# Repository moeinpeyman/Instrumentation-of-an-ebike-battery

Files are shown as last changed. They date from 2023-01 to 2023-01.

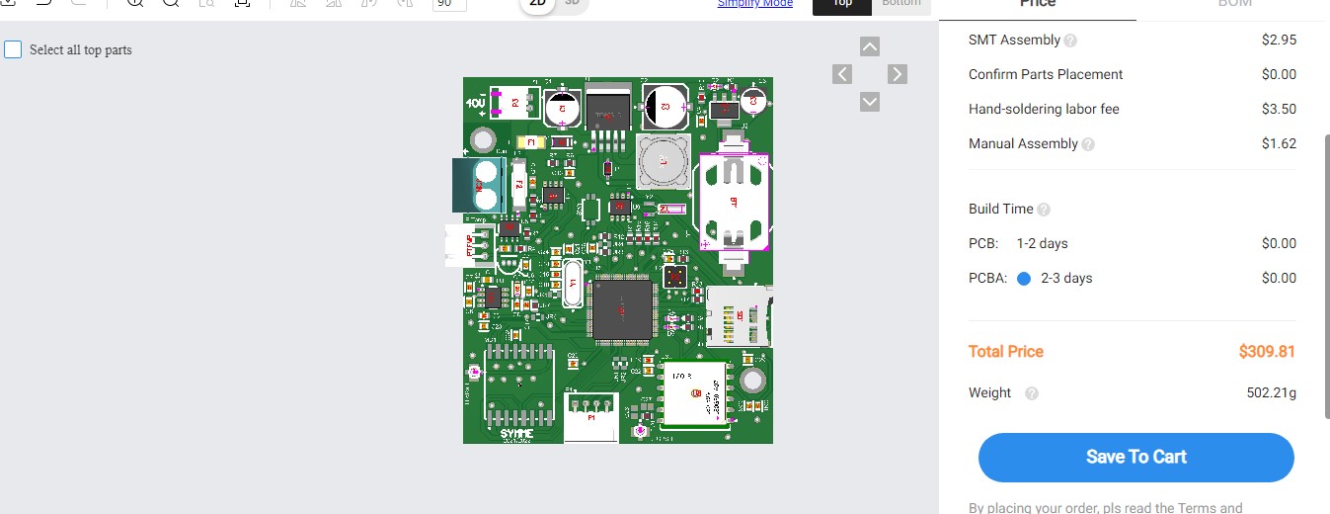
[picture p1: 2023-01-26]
PCB/JLPCB/Screenshot 2022-09-02 162259.jpg

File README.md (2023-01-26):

## PCB is designed in Altium designer and ordered from JLCPCB.



## ST-LINK/V2 for upload the code:



## The installed PCB in the e-bike battery:



## ADC configuration in STM32CubeIDE:



## SPI configuration for SD card in STM32CubeIDE:
ref:https://01001000.xyz/2020-08-09-Tutorial-STM32CubeIDE-SD-card/



## The Main.c code is available here:

https://github.com/moeinpeyman/Instrumentation-of-an-ebike-battery/blob/main/Ebike_battery_data_logging/Core/Src/main.c

## Testing roath:



## Result:


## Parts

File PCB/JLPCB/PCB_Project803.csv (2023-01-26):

Comment | Description | Designator | Footprint | LibRef | Quantity | LCSC part#
796136-1 |  | BT1 | TECO-796136-1_V | CMP-1684-00006-2 | 1 | C70377
100uF |  | C1 | FP-UWT1H101MNL1GS-MFG | CMP-2000-07373-2 | 1 | C445063
1000uF |  | C2 | FP-SVPF-F12-MFG | CMP-05427-000075-1 | 1 | C236289
100uf |  | C3 | FP-SC-MFG | CMP-05427-000027-1 | 1 | C128464
10uF |  | C4, C6, C30, C32 | FP-GRM21B-0_1-IPC_C | CMP-2007-03453-2 | 4 | C77075
1uF |  | C5 | FP-T491A105K016AT-MFG | CMP-2000-07186-2 | 1 | C116269
0.1uF |  | C7, C8, C9, C13, C19, C20, C21, C22, C23, C29, C31 | FP-C0805C-DN-MFG | CMP-2100-03606-3, CMP-2007-00279-2 | 11 | C49678
1nf |  | C10, C11, C12 | CAPC2013X70X45NL10T25 | CMP-2100-03606-3 | 3 | C303890
15pF |  | C14, C15 | FP-C0805C-DN-MFG | CMP-2007-00279-2 | 2 | C396747
10nF |  | C16, C25 | FP-C0805C-DN-MFG | CMP-2007-00279-2 | 2 | C188188
1uF |  | C17, C26 | FP-C0805C-DN-MFG | CMP-2007-00279-2 | 2 | C89190
100nF |  | C18 | FP-C0805C-DN-MFG | CMP-2007-00279-2 | 1 | C49678
4.7uF |  | C24 | FP-C0805C-DN-MFG | CMP-2007-00279-2 | 1 | C215908
0.1uF |  | C33 | FP-CC0805-0_85-MFG | CMP-2100-03606-3 | 1 | C49678
1N4007 SMD |  | D1 | FP-1N4007_SMD-IPC_C | CMP-12389-000001-1 | 1 | C727081
APT2012MGC |  | D2, D4, D5 | FP-APT2012MGC-MFG | CMP-1426-00010-2 | 3 | C138557
1N5822US |  | D3 | MCSM-D-5B-2_L | CMP-0303-00003-3 | 1 | C402219
1.5A |  | F1 | FP-0679H-MFG | CMP-2000-05188-2 | 1 | C178994
20A |  | F2 | FP-0456-MFG | CMP-08605-000068-1 | 1 | C99552
73412-0110 |  | JGPS1, JLoRa1 | MOLX-73412-0110_V | CMP-1676-00003-1 | 2 | C411563
PC Terminal Block |  | JCin | PHOE-1714955_V | CMP-2000-05797-1 | 1 | C480584
0R |  | JR3, JR7 | FP-RMCF0805-MFG | CMP-26527-000017-1 | 6 | C25275
150 µH |  | L1 | WE-PD-XL | CMP-0227-00206-1 | 1 | C169397
RFM95W-868S2 |  | MD1 | FP-RFM95W-868S2-MFG | CMP-204316-000001-1 | 1 | C2844472
USART Interface Port |  | P1 | JST-S4B-XH-A(LF)(SN)_V | CMP-1755-00007-1 | 1 | C163037
HTSW-102-07-G-D |  | P2 | FP-HTSW-102-07-G-D-MFG | CMP-02766-000010-1 | 1 | C66690
S2B-XH-A(LF)(SN) |  | P3 | JST-S2B-XH-A(LF)(SN)_V | CMP-1755-00005-1 | 1 | C157931
S3B-XH-A(LF)(SN) |  | PTemp | JST-S3B-XH-A(LF)(SN)_V | CMP-1755-00006-1 | 1 | C157928
330R |  | R1, R8, R9 | FP-CRCW0805-e3-MFG | CMP-02407-004193-1 | 3 | C17630
5.6K |  | R2, R3, R4, R5 | FP-CRCW0805-e3-MFG | CMP-02407-004193-1 | 4 | C4382
510K |  | R6 | FP-CRCW0805-e3-MFG | CMP-02407-004193-1 | 1 | C17724
30K |  | R7 | FP-CRCW0805-e3-MFG | CMP-02407-004193-1 | 1 | C422839
0R |  | R10, R19 | FP-CRCW0805-e3-MFG | CMP-02407-004193-1 | 2 | C25275
10K |  | R11, R12, R13, R14, R15, R16, R17, R18 | FP-CRCW0805-e3-MFG | CMP-02407-004193-1 | 8 | C478887
473521001 |  | SD1 | MOLX-473521001_V | CMP-2000-05848-1 | 1 | C381079
LM2576-5.0WU |  | U1 | FP-TO263-5LD-PL-1-MFG | CMP-0069-00269-3 | 1 | C77782
LM1117IMP-3.3/NOPB |  | U2 | DCY0004A_N | CMP-0062-01631-4 | 1 | C126027
REF192GSZ |  | U3 | ADI-R-8_M | CMP-0784-00133-1 | 1 | C27314
LM358MX/NOPB |  | U4 | D0008A_L | CMP-2000-07568-1 | 1 | C16416
ACS712ELCTR-20A-T |  | U5 | FP-LC-8-IPC_C | CMP-0826-00001-2 | 1 | C10681
STM32F103VET6TR |  | U7 | STM-LQFP100_L | CMP-0237-00166-3 | 1 | C8314
L80-M39 |  | U8 | QUEC-L80-M39-12_V | CMP-2000-05325-1 | 1 | C133488
DS1307Z+T&R |  | U9 | S8+2_L | CMP-0254-00305-1 | 1 | C9868
8Mhz |  | Y1 | FOX-FOXSLF080-20 | CMP-1749-00002-1 | 1 | C295071
AB26TRB-32.768KHZ-T |  | Y2 | FP-AB26TRB-MFG | CMP-27762-006068-1 | 1 | C179645

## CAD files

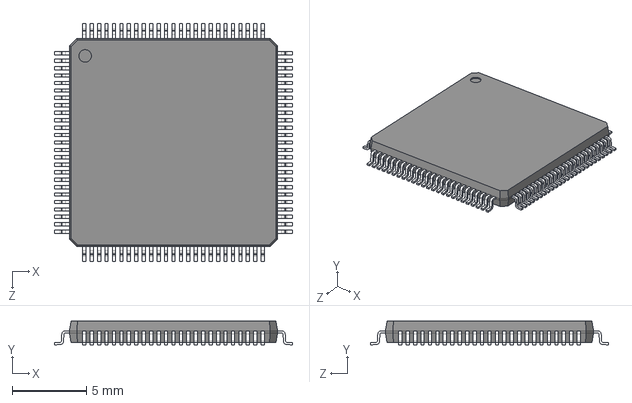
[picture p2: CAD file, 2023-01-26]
PCB/STM32F103VDT7.STEP
16.0 x 1.60 x 16.0 mm

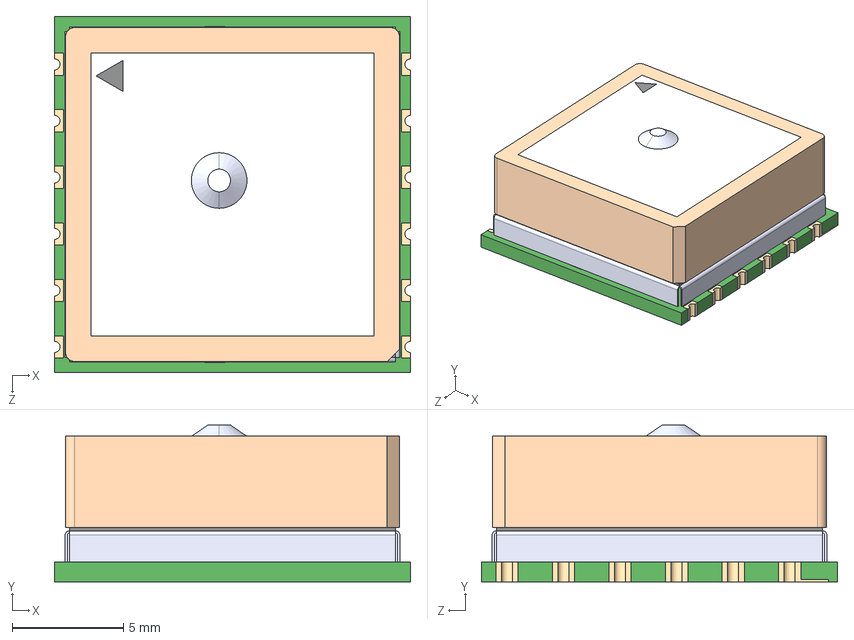
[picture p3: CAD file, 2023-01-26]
PCB/L80-M39--3DModel-STEP-56544.STEP
16.0 x 7.05 x 16.0 mm

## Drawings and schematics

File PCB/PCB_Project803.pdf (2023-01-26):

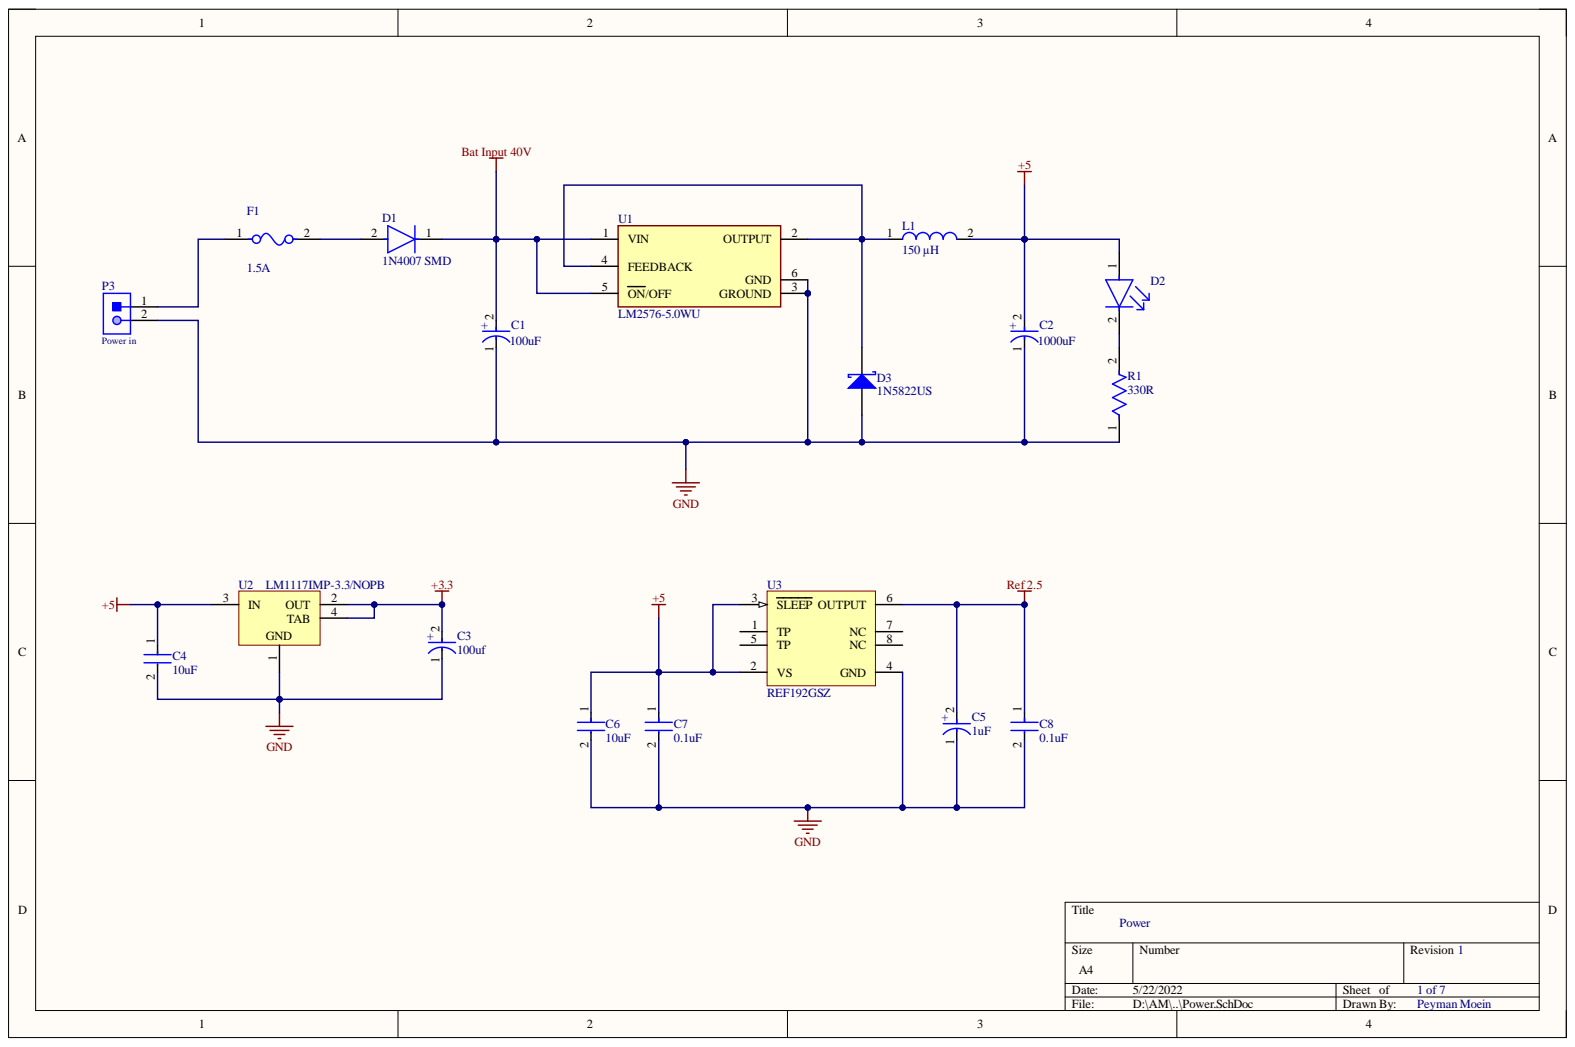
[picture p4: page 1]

FEEDBACK 4
GND ON/OFF 5 | 6

Size A4 | Number | Revision 1

Date: 5/22/2022 | Sheet of 1 of 7
File: D:\AM\..\Power.SchDoc | Drawn By: Peyman Moein

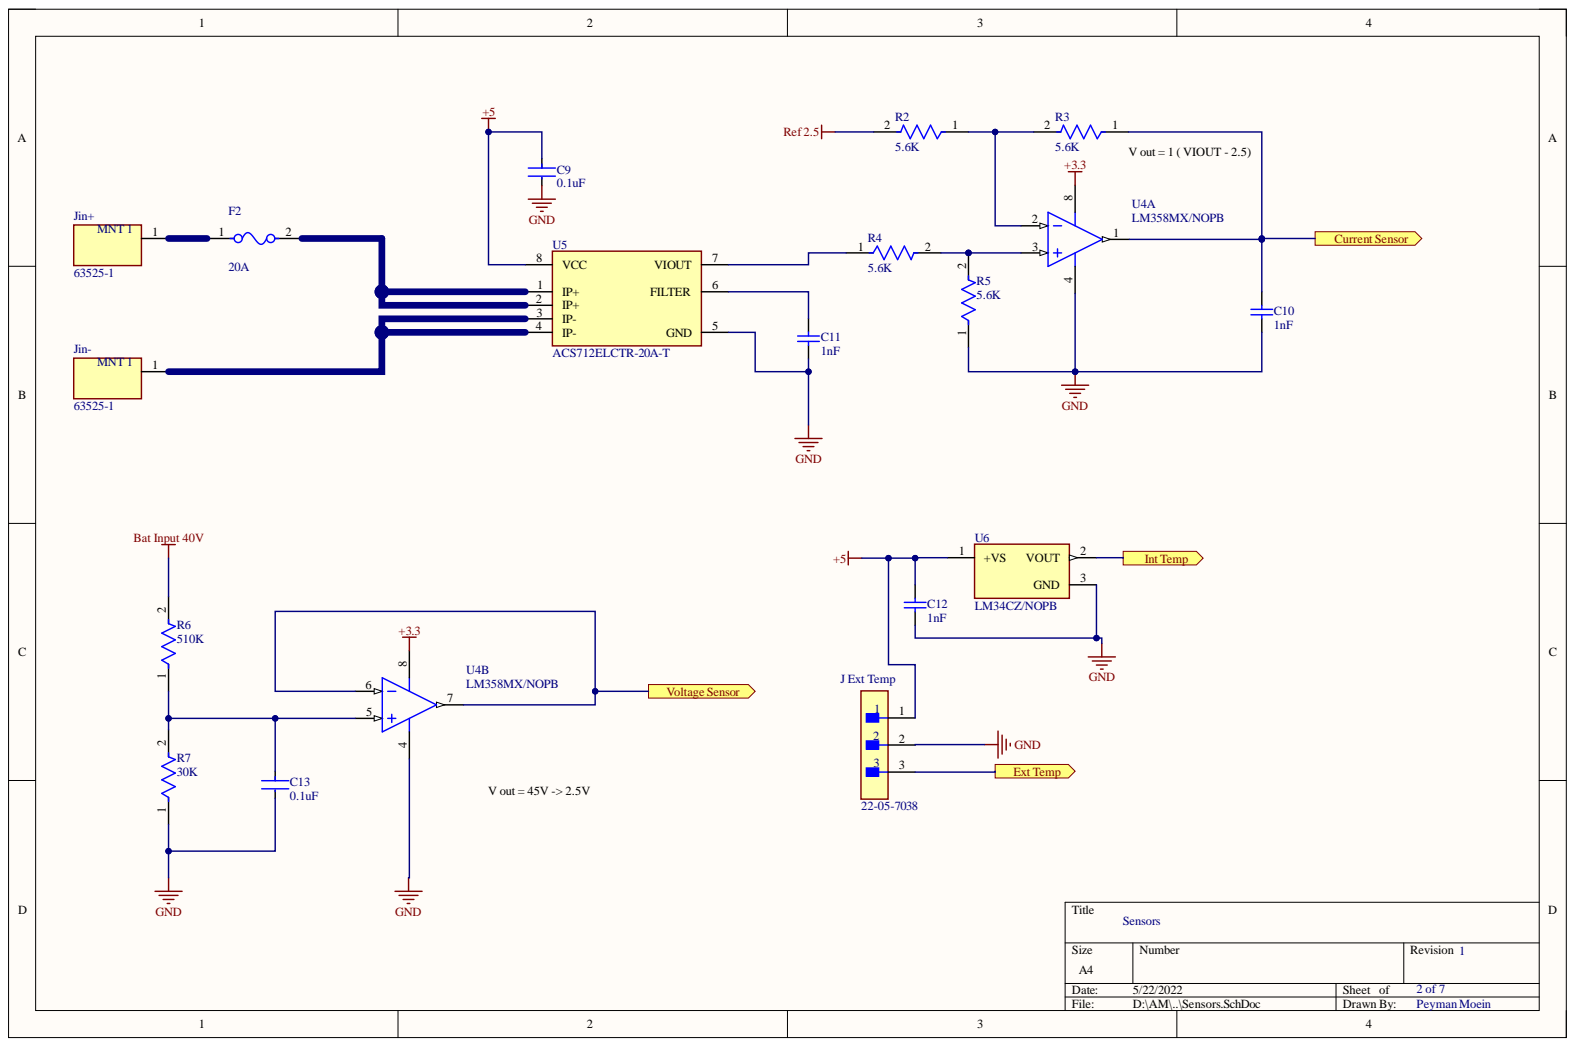
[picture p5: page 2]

Size A4 | Number | Revision 1

Date: 5/22/2022 | 2 of 7 Sheet of
File: D:\AM\..\Sensors.SchDoc | Drawn By: Peyman Moein

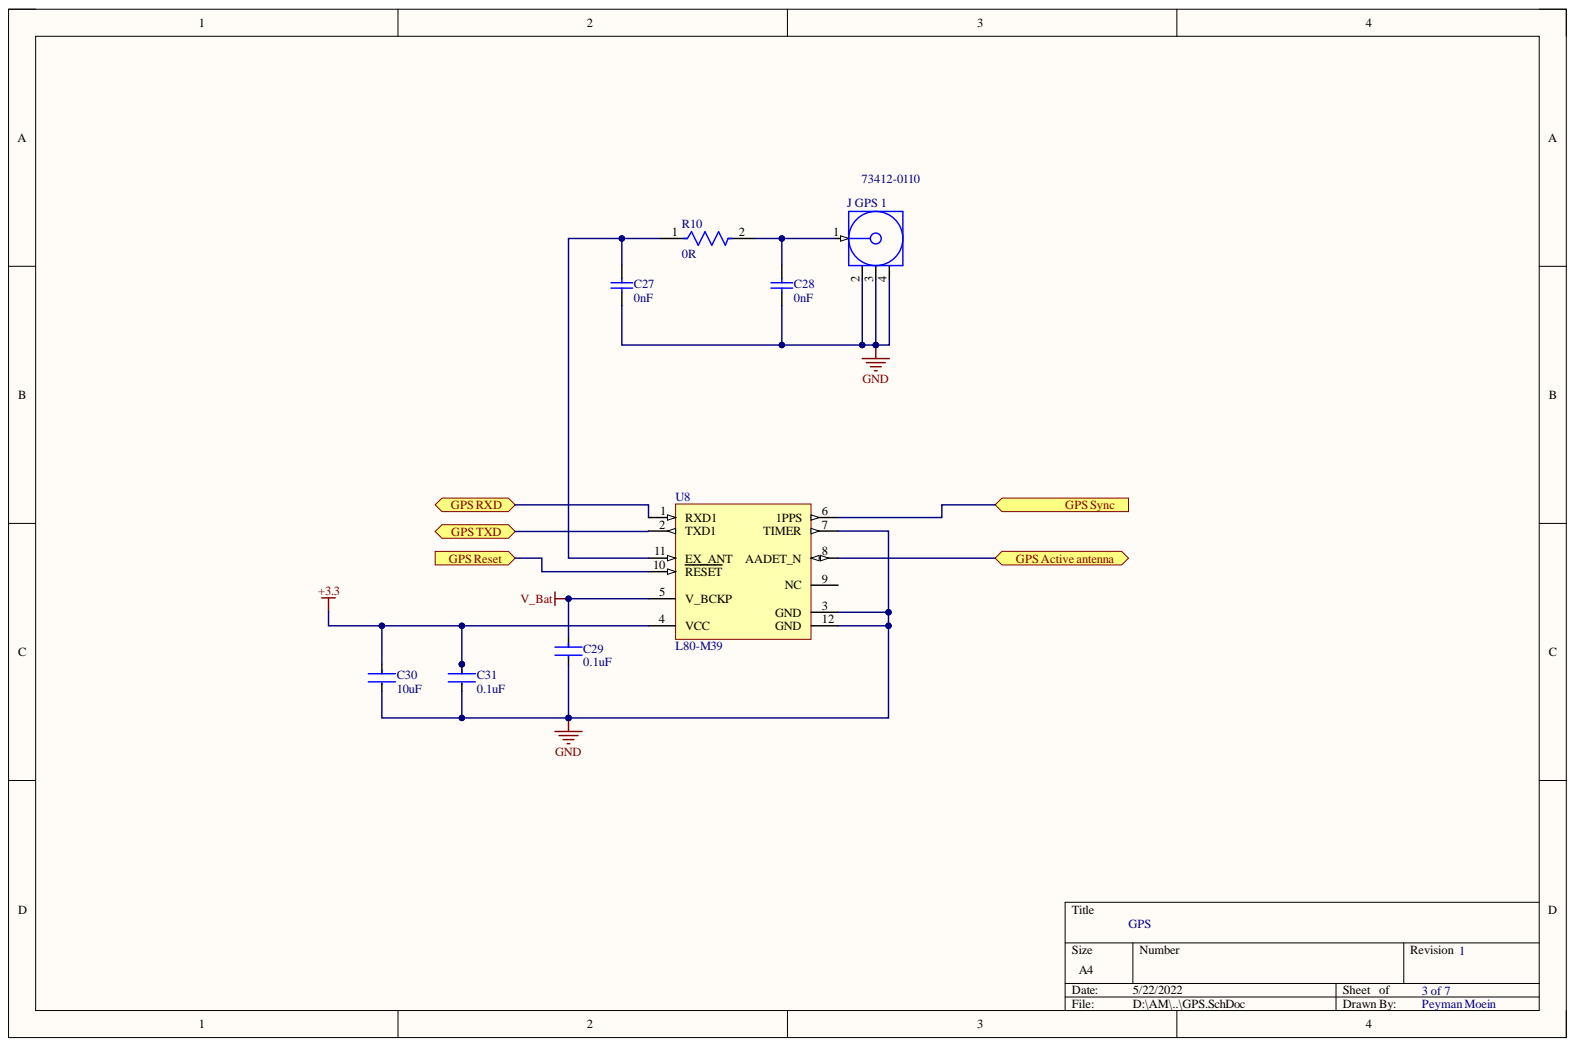
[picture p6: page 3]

Size A4 | Number | Revision 1

Date: 5/22/2022 | Sheet of 3 of 7
File: D:\AM\..\GPS.SchDoc | Drawn By: Peyman Moein

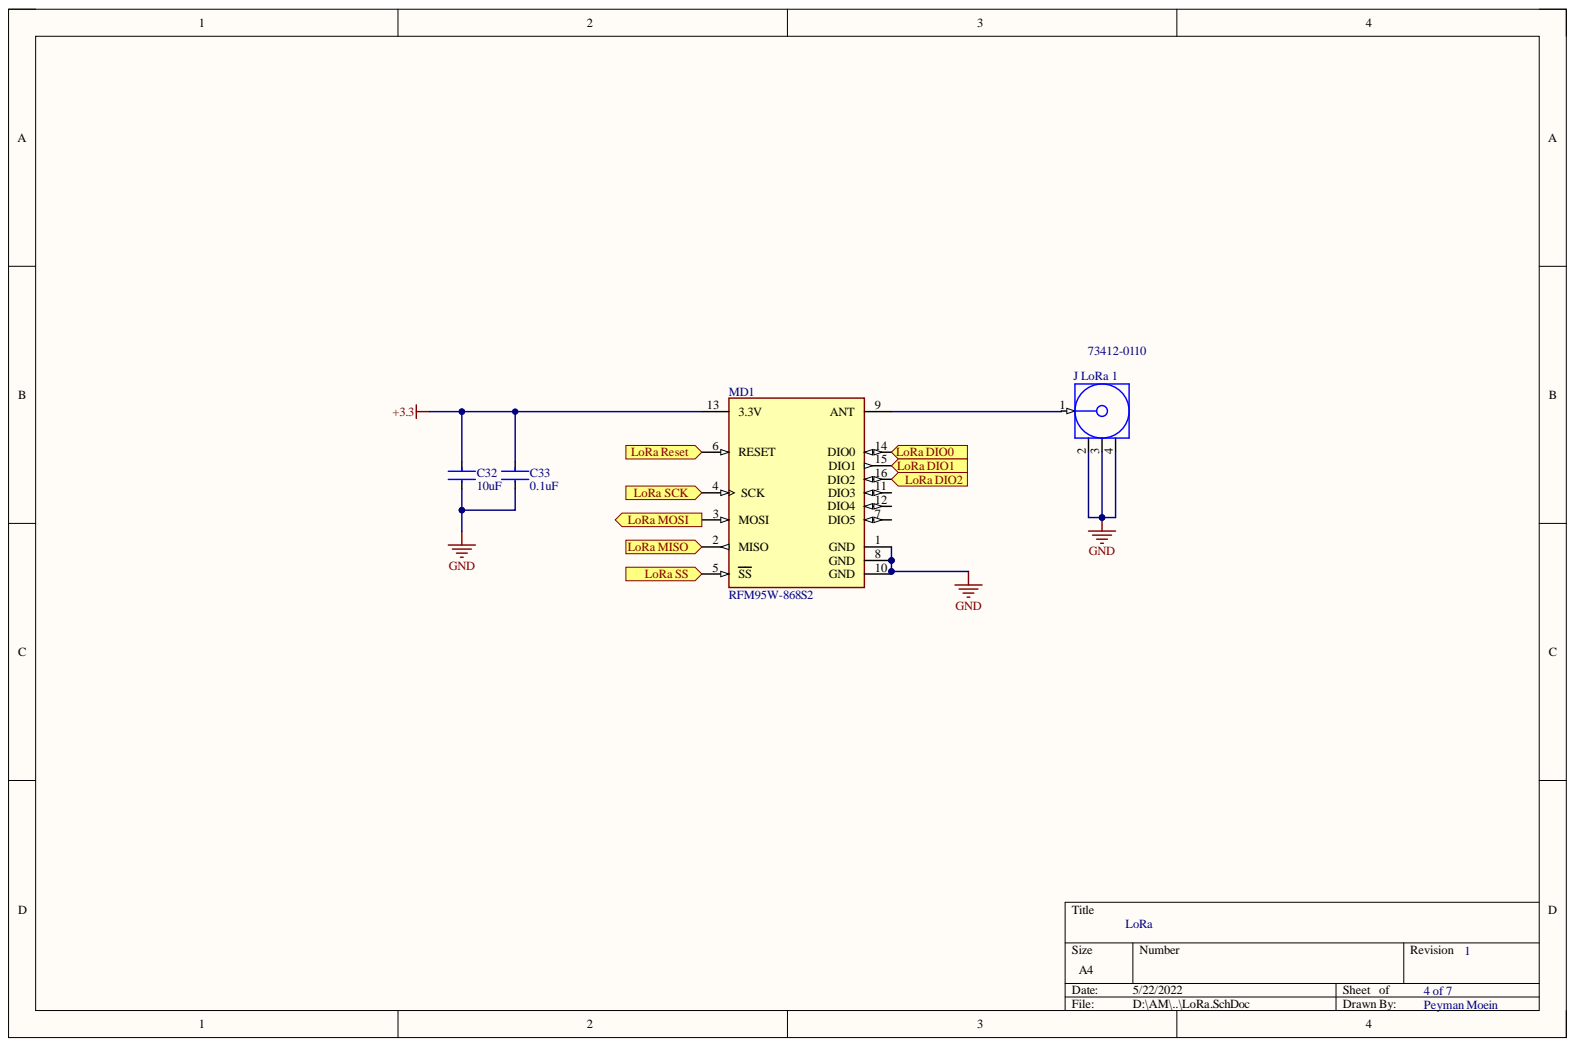
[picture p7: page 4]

Size A4 | Number | Revision 1

Date: 5/22/2022 | Sheet of 4 of 7
File: D:\AM\..\LoRa.SchDoc | Drawn By: Peyman Moein

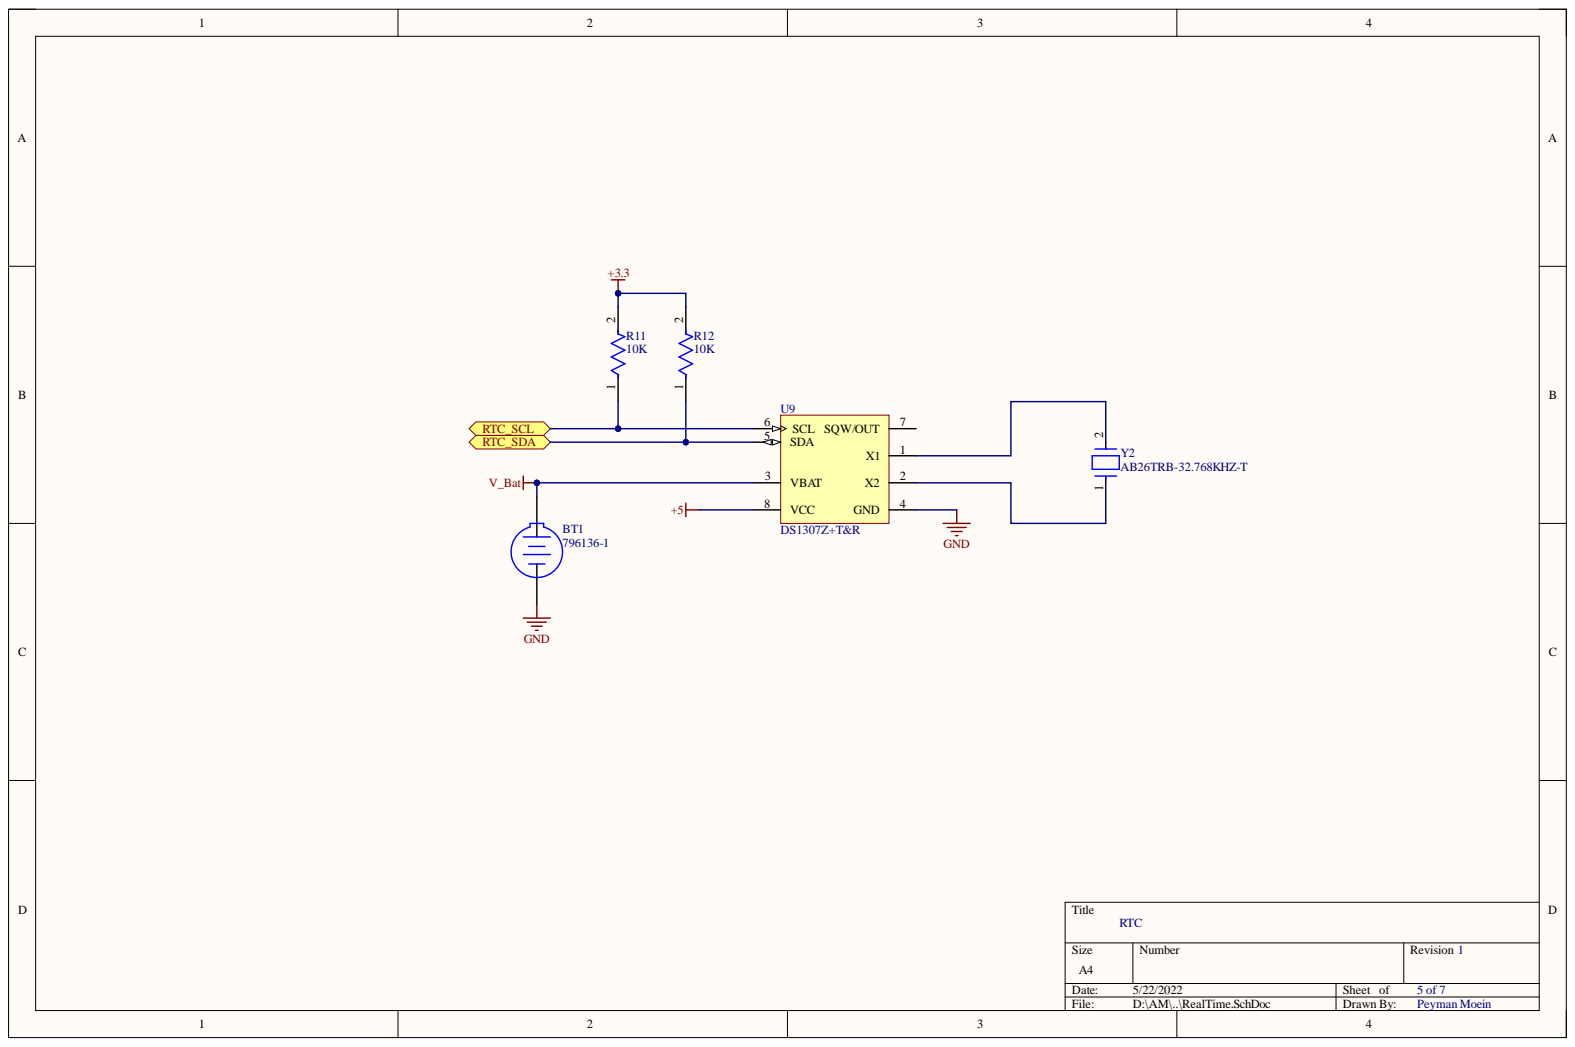
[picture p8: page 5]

Siz e A4 | Numb e r | R evisio n 1

Da te : 5/22/202 2 | She et of 5 of 7
File : D:\AM\. .\R e alTime . S c hD o c | Dr awn B y : P eyman Moe in

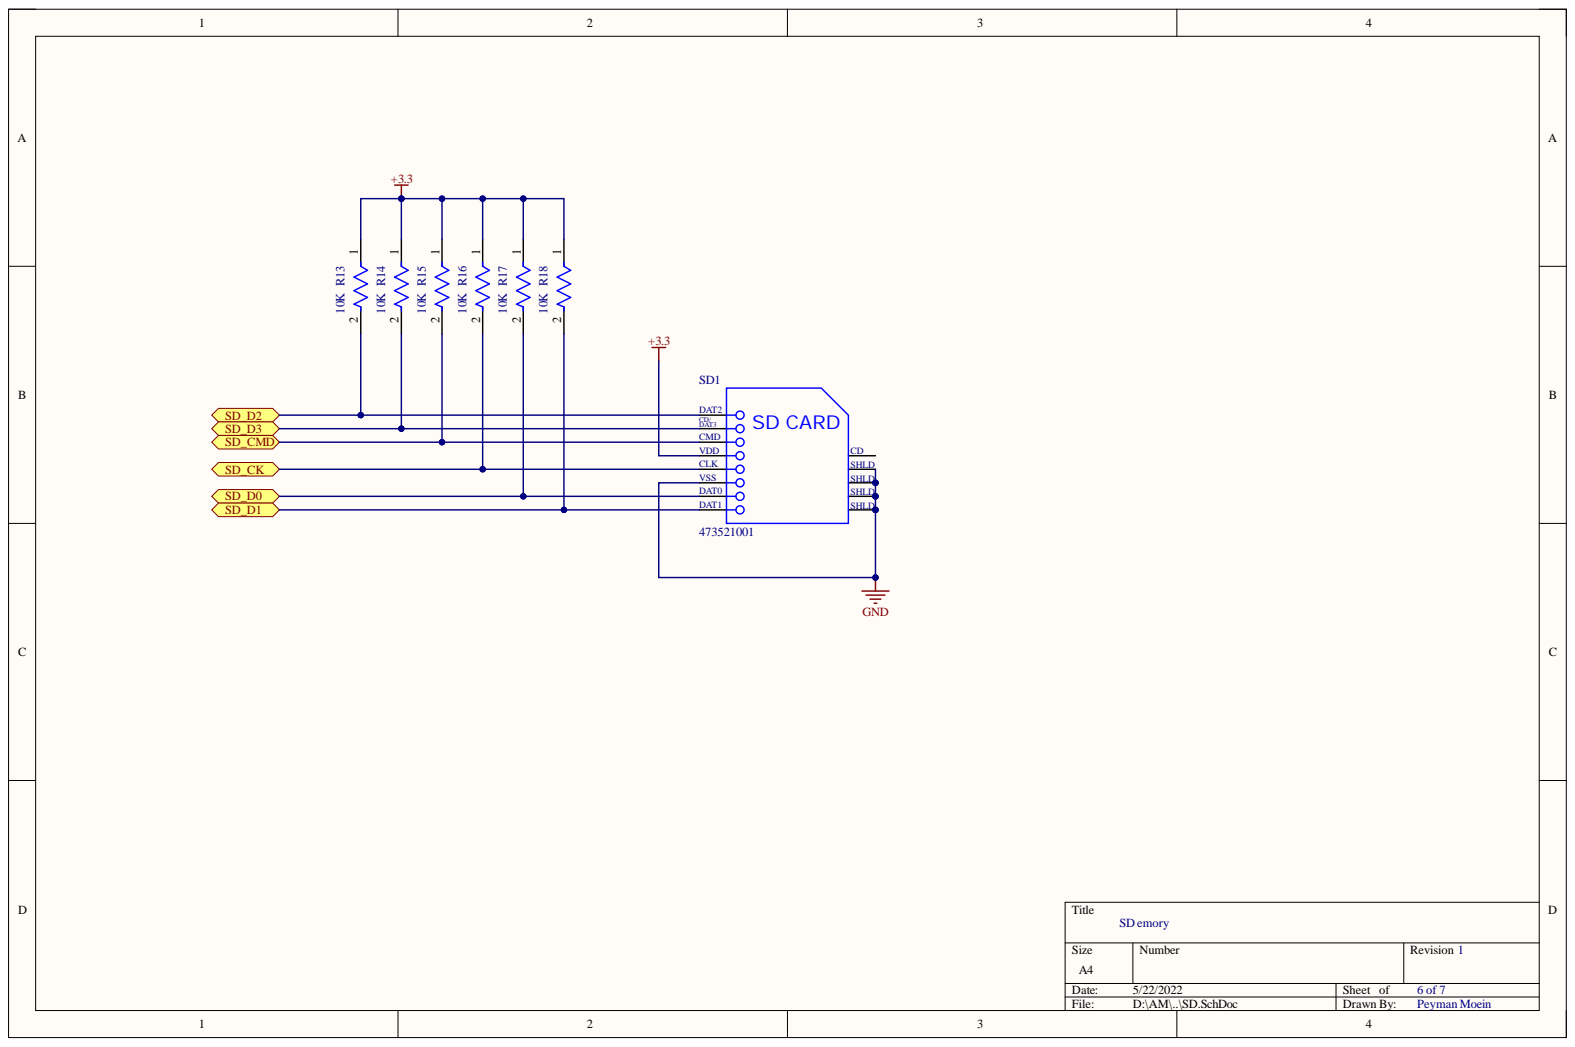
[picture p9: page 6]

Siz e A4 | Numb e r | R evisio n 1

Da te : 5/22/202 2 | She et of 6 of 7
File : D:\AM\. .\SD. S c hD o c | Dr awn B y : P eyman Moe in

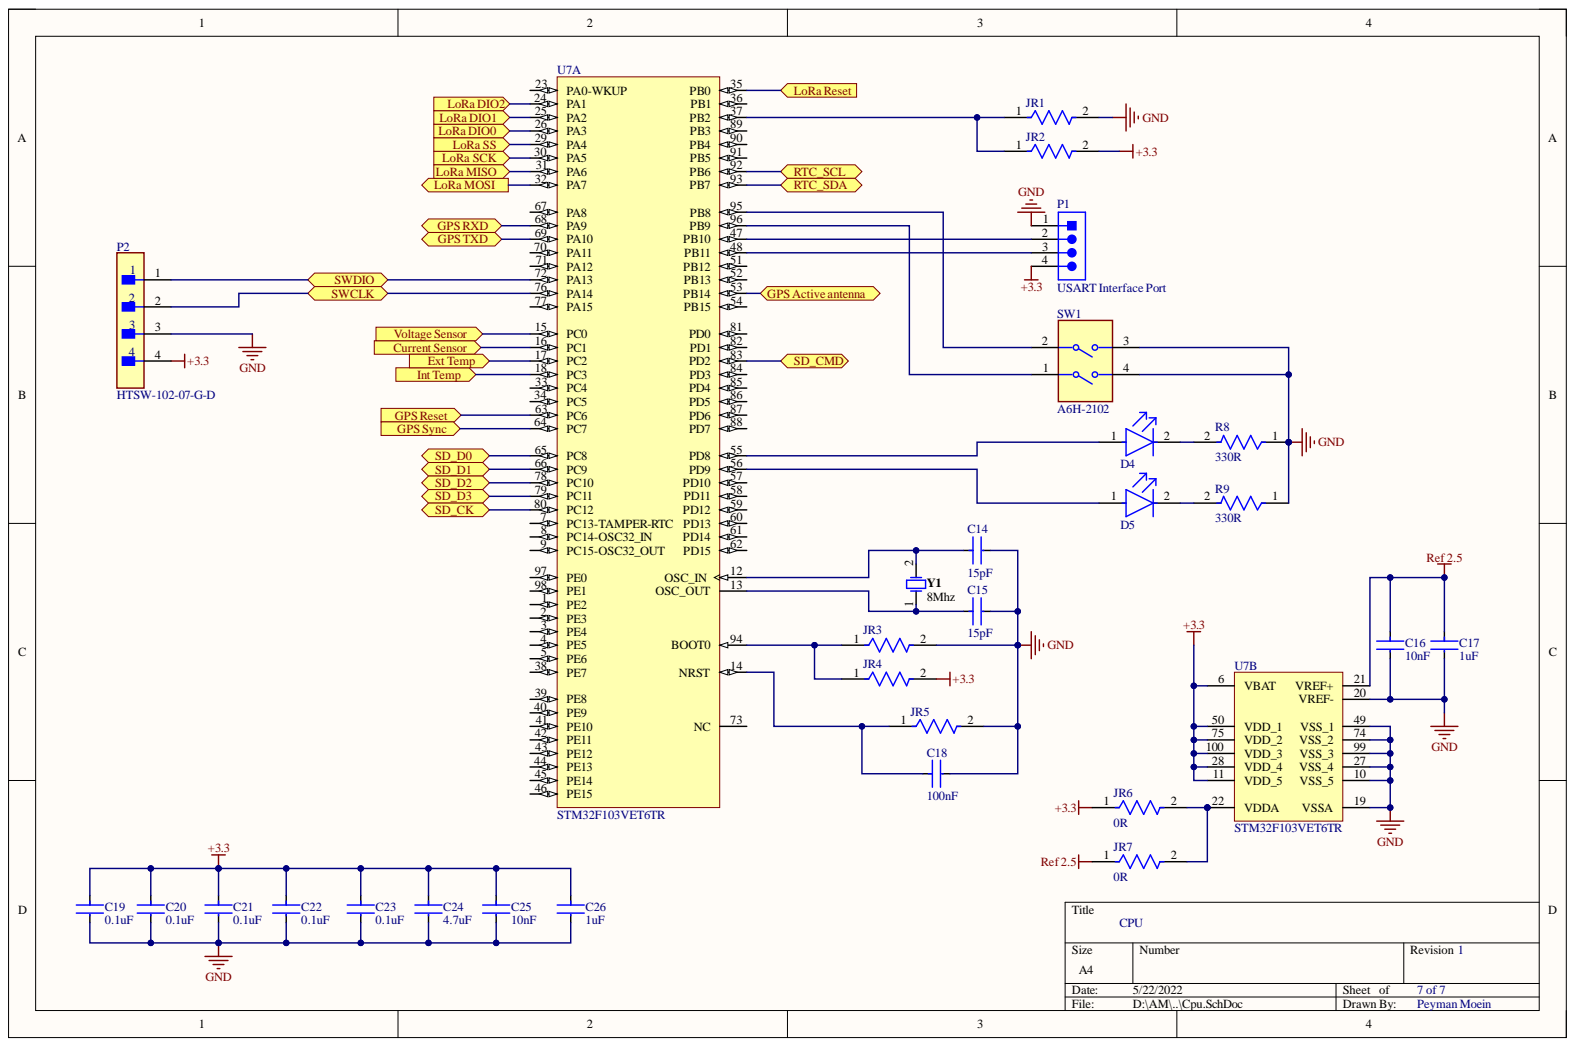
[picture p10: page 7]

SD_CMD | 1 | 4

Size A4 | Number | Revision 1

Date: 5/22/2022 | Sheet of 7 of 7
File: D:\AM\..\Cpu.SchDoc | Drawn By: Peyman Moein

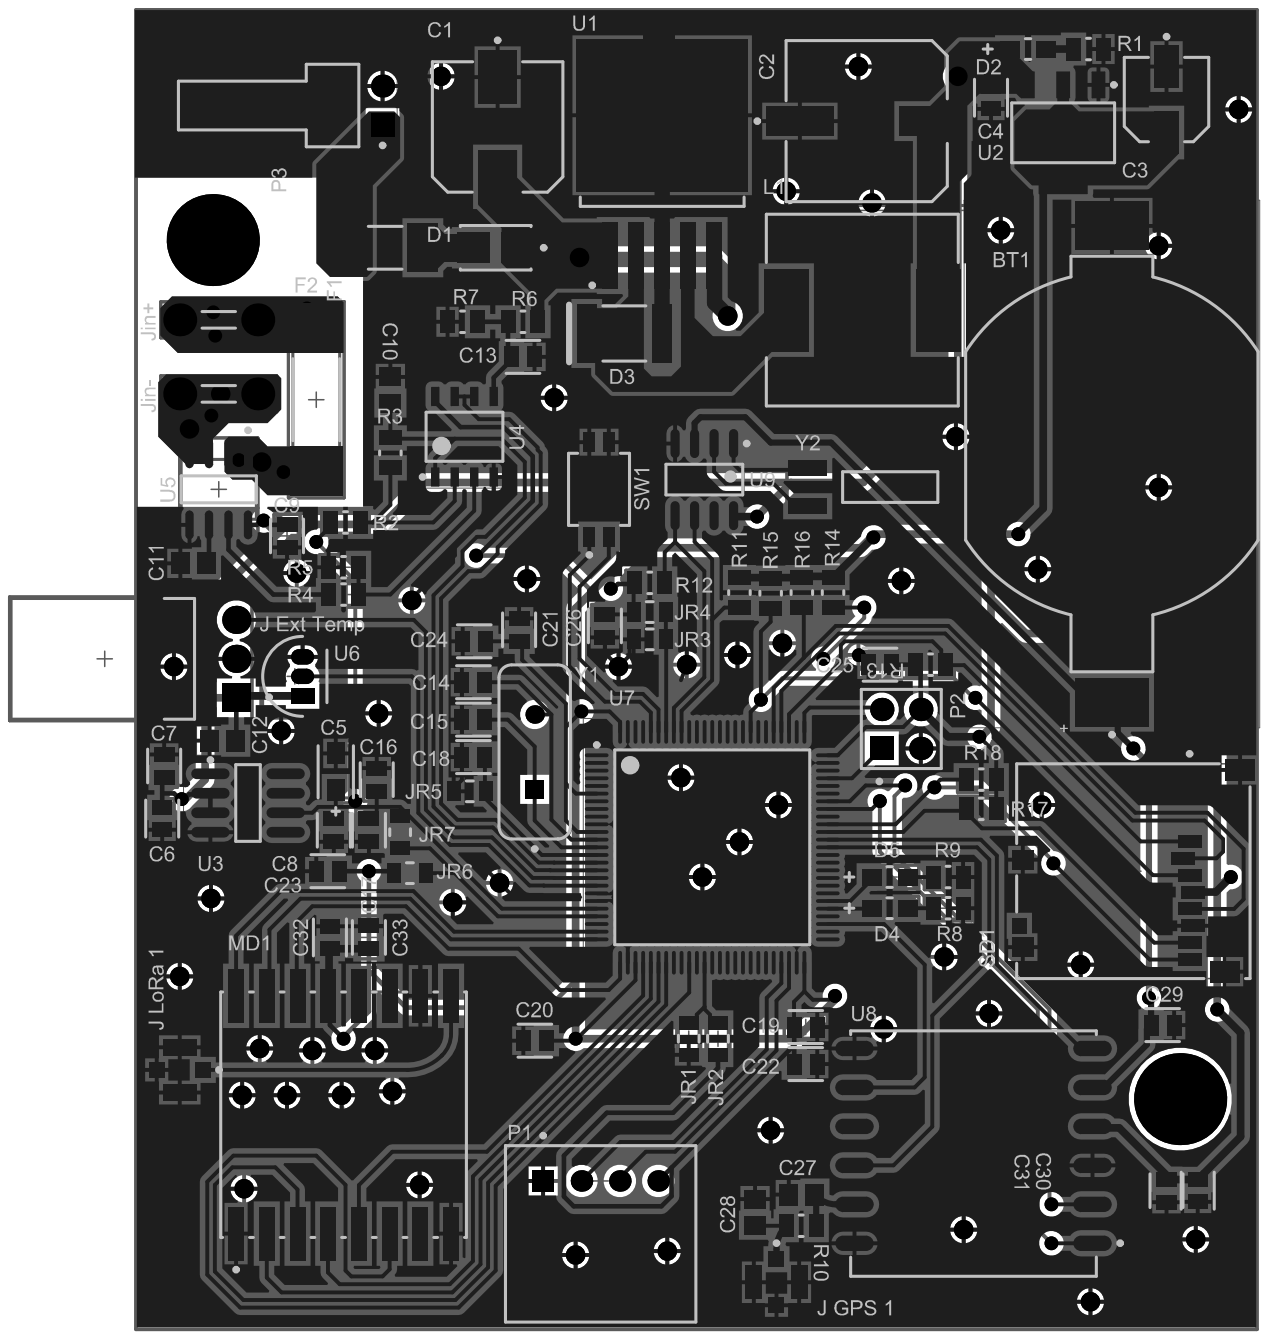
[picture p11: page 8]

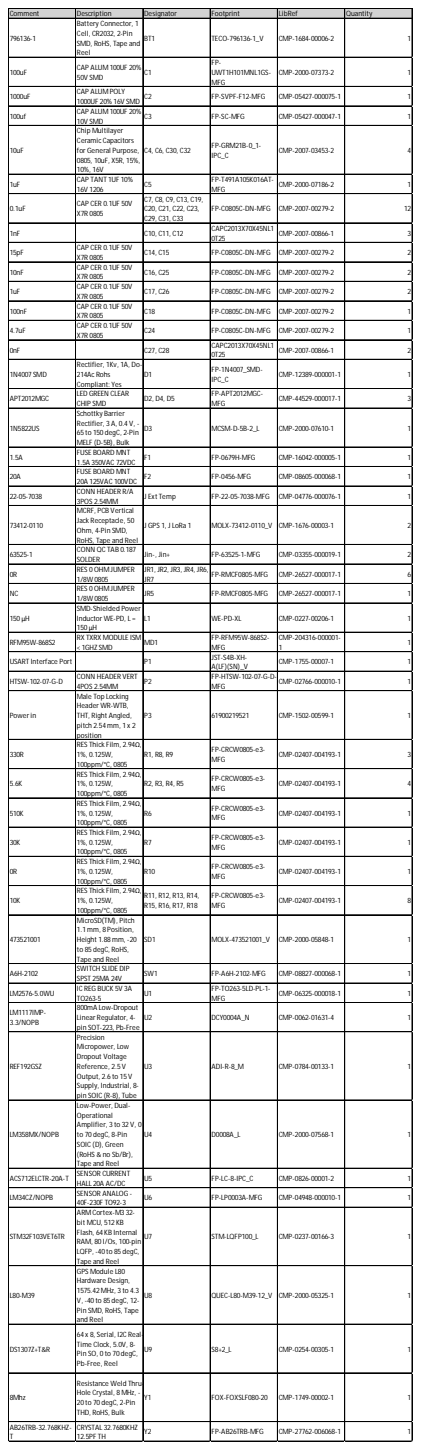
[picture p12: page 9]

Comment | Description | Designator | Footprint | LibRef | Quantity
796136-1 | Battery Connector, 1 Cell, CR2032, 2-Pin SMD, RoHS, Tape and Reel | BT1 | TECO-796136-1_V | CMP-1684-00006-2 | | 1

100uF | CAP ALUM 100UF 20% 50V SMD | C1 | FP-UWT1H101MNL1GS-MFG | CMP-2000-07373-2 | | 1

1000uF | CAP ALUM POLY 1000UF 20% 16V SMD | C2 | FP-SVPF-F12-MFG | CMP-05427-000075-1 | | 1

100uf | CAP ALUM 100UF 20% 10V SMD | C3 | FP-SC-MFG | CMP-05427-000047-1 | | 1

10uF | Chip Multilayer Ceramic Capacitors for General Purpose, 0805, 10uF, X5R, 15%, 10%, 16V | C4, C6, C30, C32 | FP-GRM21B-0_1-IPC_C | CMP-2007-03453-2 | | 4

1uF | CAP TANT 1UF 10% 16V 1206 | C5 | FP-T491A105K016AT-MFG | CMP-2000-07186-2 | | 1

0.1uF | CAP CER 0.1UF 50V X7R 0805 | C7, C8, C9, C13, C19, C20, C21, C22, C23, C29, C31, C33 | FP-C0805C-DN-MFG | CMP-2007-00279-2 | 12

1nF | | C10, C11, C12 | CAPC2013X70X45NL1 0T25 | CMP-2007-00866-1 | | 3

15pF | CAP CER 0.1UF 50V X7R 0805 | C14, C15 | FP-C0805C-DN-MFG | CMP-2007-00279-2 | | 2

10nF | CAP CER 0.1UF 50V X7R 0805 | C16, C25 | FP-C0805C-DN-MFG | CMP-2007-00279-2 | | 2

1uF | CAP CER 0.1UF 50V X7R 0805 | C17, C26 | FP-C0805C-DN-MFG | CMP-2007-00279-2 | | 2

100nF | CAP CER 0.1UF 50V X7R 0805 | C18 | FP-C0805C-DN-MFG | CMP-2007-00279-2 | | 1

4.7uF | CAP CER 0.1UF 50V X7R 0805 | C24 | FP-C0805C-DN-MFG | CMP-2007-00279-2 | | 1

0nF | | C27, C28 | CAPC2013X70X45NL1 0T25 | CMP-2007-00866-1 | | 2

1N4007 SMD | Rectifier, 1Kv, 1A, Do-214Ac Rohs Compliant: Yes | D1 | FP-1N4007_SMD-IPC_C | CMP-12389-000001-1 | | 1

APT2012MGC | LED GREEN CLEAR CHIP SMD | D2, D4, D5 | FP-APT2012MGC-MFG | CMP-44529-000017-1 | | 3

1N5822US | Schottky Barrier Rectifier, 3 A, 0.4 V, -65 to 150 degC, 2-Pin MELF (D-5B), Bulk | D3 | MCSM-D-5B-2_L | CMP-2000-07610-1 | | 1

1.5A | FUSE BOARD MNT 1.5A 350VAC 72VDC | F1 | FP-0679H-MFG | CMP-16042-000005-1 | | 1

20A | FUSE BOARD MNT 20A 125VAC 100VDC | F2 | FP-0456-MFG | CMP-08605-000068-1 | | 1

22-05-7038 | CONN HEADER R/A 3POS 2.54MM | J Ext Temp | FP-22-05-7038-MFG | CMP-04776-000076-1 | | 1

73412-0110 | MCRF, PCB Vertical Jack Receptacle, 50 Ohm, 4-Pin SMD, RoHS, Tape and Reel | J GPS 1, J LoRa 1 | MOLX-73412-0110_V | CMP-1676-00003-1 | | 2

63525-1 | CONN QC TAB 0.187 SOLDER | Jin-, Jin+ | FP-63525-1-MFG | CMP-03355-000019-1 | | 2

0R | RES 0OHM JUMPER 1/8W 0805 | JR1, JR2, JR3, JR4, JR6, JR7 | FP-RMCF0805-MFG | CMP-26527-000017-1 | | 6

NC | RES 0OHM JUMPER 1/8W 0805 | JR5 | FP-RMCF0805-MFG | CMP-26527-000017-1 | | 1

150 µH | SMD-Shielded Power Inductor WE-PD, L = 150 µH | L1 | WE-PD-XL | CMP-0227-00206-1 | | 1

RFM95W-868S2 | RX TXRX MODULE ISM < 1GHZ SMD | MD1 | FP-RFM95W-868S2-MFG | CMP-204316-000001-1 | | 1

USART Interface Port | | P1 | JST-S4B-XH-A(LF)(SN)_V | CMP-1755-00007-1 | | 1

HTSW-102-07-G-D | CONN HEADER VERT 4POS 2.54MM | P2 | FP-HTSW-102-07-G-D-MFG | CMP-02766-000010-1 | | 1

Power in | Male Top Locking Header WR-WTB, THT, Right Angled, pitch 2.54mm, 1 x 2 position | P3 | 61900219521 | CMP-1502-00599-1 | | 1

330R | RES Thick Film, 2.94Ω, 1%, 0.125W, 100ppm/°C, 0805 | R1, R8, R9 | FP-CRCW0805-e3-MFG | CMP-02407-004193-1 | | 3

5.6K | RES Thick Film, 2.94Ω, 1%, 0.125W, 100ppm/°C, 0805 | R2, R3, R4, R5 | FP-CRCW0805-e3-MFG | CMP-02407-004193-1 | | 4

510K | RES Thick Film, 2.94Ω, 1%, 0.125W, 100ppm/°C, 0805 | R6 | FP-CRCW0805-e3-MFG | CMP-02407-004193-1 | | 1
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

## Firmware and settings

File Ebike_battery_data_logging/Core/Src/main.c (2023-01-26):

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
/* Includes ------------------------------------------------------------------*/
#include "main.h"
#include "fatfs.h"

/* USER CODE BEGIN Includes */
#include <stdio.h>
#include <string.h>
#include <stdarg.h>

/* USER CODE END Includes */

ADC_HandleTypeDef hadc1;

SPI_HandleTypeDef hspi2;

void SystemClock_Config(void);
static void MX_GPIO_Init(void);
static void MX_ADC1_Init(void);
static void MX_SPI2_Init(void);
/* USER CODE BEGIN PFP */
void myprintf(const char *fmt, ...);
static void select_ch10(void);
static void select_ch11(void);
static void select_ch12(void);
static void select_ch13(void);

float MAP(float in_v,float Min_Ana_Val,float Max_Ana_Val,float Min_Dig_Val,float Max_Dig_Val);
/* USER CODE END PFP */

/**
  * @brief  The application entry point.
  * @retval int
  */
int main(void)
{
  /* MCU Configuration--------------------------------------------------------*/

  /* Reset of all peripherals, Initializes the Flash interface and the Systick. */
  HAL_Init();

  /* USER CODE BEGIN Init */
  uint32_t  Counter = 0;
  uint16_t  Ana_Vol = 0;
  uint16_t  Ana_Vol2 = 0;

  uint16_t  Vol = 0;
  uint16_t  Cur = 0;
  uint16_t  TempE = 0;
  uint16_t  TempI = 0;
  /* USER CODE END Init */

  /* Configure the system clock */
  SystemClock_Config();

  /* Initialize all configured peripherals */
  MX_GPIO_Init();
  MX_ADC1_Init();
  MX_SPI2_Init();
  MX_FATFS_Init();
  /* USER CODE BEGIN 2 */


  myprintf("\r\n~ SD card demo by kiwih ~\r\n\r\n");
  HAL_Delay(1000); //a short delay is important to let the SD card settle

  //some variables for FatFs
  FATFS FatFs; 	//Fatfs handle
  FIL fil; 		//File handle
  FRESULT fres; //Result after operations

	//Open the file system
  fres = f_mount(&FatFs, "", 1); //1=mount now
  if (fres != FR_OK) {
  myprintf("f_mount error (%i)\r\n", fres);
  Error_Handler();
  }

  //Let's get some statistics from the SD card
  DWORD free_clusters, free_sectors, total_sectors;

  FATFS* getFreeFs;

  fres = f_getfree("", &free_clusters, &getFreeFs);
  if (fres != FR_OK) {
  myprintf("f_getfree error (%i)\r\n", fres);
  Error_Handler();
  }

  //Formula comes from ChaN's documentation
  total_sectors = (getFreeFs->n_fatent - 2) * getFreeFs->csize;
  free_sectors = free_clusters * getFreeFs->csize;

  myprintf("SD card stats:\r\n%10lu KiB total drive space.\r\n%10lu KiB available.\r\n", total_sectors / 2, free_sectors / 2);


  BYTE WriteBuf[100];

    //open Data.csv file" FA_CREATE_ALWAYS,FA_OPEN_ALWAYS
  fres = f_open(&fil, "Data.csv", FA_WRITE | FA_CREATE_ALWAYS|FA_OPEN_ALWAYS);
  if(fres == FR_OK) {
  myprintf("I was able to open 'Data.csv' for writing\r\n");
  } else {
  myprintf("f_open error (%i)\r\n", fres);
  Error_Handler();
  }

  //(char*)WriteBuf
  sprintf(WriteBuf,"Counter,Voltage,Current,Bat Temp,Ambient Temp\r\n");
  UINT bytesWrote;
  fres = f_write(&fil, WriteBuf, 47, &bytesWrote);
  if(fres == FR_OK) {
  myprintf("Wrote %i bytes to 'write.txt'!\r\n", bytesWrote);
  } else {
  myprintf("f_write error (%i)\r\n");
  Error_Handler();
  }




  /* USER CODE END 2 */

  /* Infinite loop */
  /* USER CODE BEGIN WHILE */

  while (1)
  {

	//Read battery Voltage
	select_ch10();
	HAL_ADC_Start(&hadc1);
	HAL_ADC_PollForConversion(&hadc1, 1000);
	Ana_Vol = HAL_ADC_GetValue(&hadc1);
	Vol =(uint16_t)MAP(Ana_Vol, 22256, 34912, 20000, 30000);
	HAL_ADC_Stop(&hadc1);
	HAL_Delay(200);

	//Read battery Current
	select_ch11();
	HAL_ADC_Start(&hadc1);
	HAL_ADC_PollForConversion(&hadc1, 1000);
	Ana_Vol = HAL_ADC_GetValue(&hadc1)-12000;
	Cur = (uint16_t)MAP(Ana_Vol, 22320, 26144, 2000, 5000);
	HAL_ADC_Stop(&hadc1);
	HAL_Delay(200);

	//Read battery temperature
	select_ch11();
	HAL_ADC_Start(&hadc1);
	HAL_ADC_PollForConversion(&hadc1, 1000);
	Ana_Vol = HAL_ADC_GetValue(&hadc1);
	TempE =(uint16_t) MAP(Ana_Vol, 0, 16,  0, 1);
	HAL_ADC_Stop(&hadc1);
	HAL_Delay(200);

	//Read ambient temperature
	select_ch12();
	HAL_ADC_Start(&hadc1);
	HAL_ADC_PollForConversion(&hadc1, 1000);
	Ana_Vol = HAL_ADC_GetValue(&hadc1);
	TempI =(uint16_t) MAP(Ana_Vol, 0, 16,  0, 1);
	HAL_ADC_Stop(&hadc1);
	HAL_Delay(200);


	//Copy in a string
	//(char*)WriteBuf
	sprintf((char*)WriteBuf,"%05d,%05d,%05d,%05d,%05d\r\n",Counter,Vol,Cur,TempI,TempE);
	UINT bytesWrote;
	fres = f_write(&fil, WriteBuf, 30, &bytesWrote);
	if(fres == FR_OK) {
	myprintf("Wrote %i bytes to 'Data.csv'!\r\n", bytesWrote);
	} else {
	myprintf("f_write error (%i)\r\n");
	Error_Handler();
	}

    f_sync(&fil);
	Counter++;
	HAL_GPIO_TogglePin(GPIOD, GPIO_PIN_8);
	HAL_Delay(1000);


  }

  //Be a tidy kiwi - don't forget to close your file!
  f_close(&fil);

  //We're done, so de-mount the drive
  f_mount(NULL, "", 0);


  /* USER CODE END 3 */
}

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
/* USER CODE BEGIN 4 */
float MAP(float in_v,float Min_Ana_Val,float Max_Ana_Val,float Min_Dig_Val,float Max_Dig_Val)
{
	return (((in_v - Min_Ana_Val)*(Max_Dig_Val - Min_Dig_Val))/(Max_Ana_Val - Min_Ana_Val))+ Min_Dig_Val;
}

static void select_ch10(void)
{
	ADC_ChannelConfTypeDef sConfig = {0};
	sConfig.Channel = ADC_CHANNEL_10;
	sConfig.Rank = ADC_REGULAR_RANK_1;
	sConfig.SamplingTime = ADC_SAMPLETIME_1CYCLE_5;
	if (HAL_ADC_ConfigChannel(&hadc1, &sConfig) != HAL_OK)
	{
	Error_Handler();
	}
}

static void select_ch11(void)
{
	ADC_ChannelConfTypeDef sConfig = {0};
	sConfig.Channel = ADC_CHANNEL_11;
	sConfig.Rank = ADC_REGULAR_RANK_1;
	if (HAL_ADC_ConfigChannel(&hadc1, &sConfig) != HAL_OK)
	{
	Error_Handler();
	}
}
static void select_ch12(void)
{
	ADC_ChannelConfTypeDef sConfig = {0};
	  sConfig.Channel = ADC_CHANNEL_12;
	  sConfig.Rank = ADC_REGULAR_RANK_1;
	  if (HAL_ADC_ConfigChannel(&hadc1, &sConfig) != HAL_OK)
	  {
	    Error_Handler();
	  }

}

static void select_ch13(void)
{
	ADC_ChannelConfTypeDef sConfig = {0};

	  /** Configure Regular Channel
	  */
	  sConfig.Channel = ADC_CHANNEL_13;
	  sConfig.Rank = ADC_REGULAR_RANK_1;
	  if (HAL_ADC_ConfigChannel(&hadc1, &sConfig) != HAL_OK)
	  {
	    Error_Handler();
	  }
}

void myprintf(const char *fmt, ...) {
  static char buffer[256];
  va_list args;
  va_start(args, fmt);
  vsnprintf(buffer, sizeof(buffer), fmt, args);
  va_end(args);

  int len = strlen(buffer);
  //HAL_UART_Transmit(&huart2, (uint8_t*)buffer, len, -1);

}
/* USER CODE END 4 */
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


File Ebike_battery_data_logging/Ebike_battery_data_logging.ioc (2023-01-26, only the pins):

Mcu.UserName=STM32F103VBTx
PA13.Signal=SYS_JTMS-SWDIO
PA14.Signal=SYS_JTCK-SWCLK
PA3.Signal=EVENTOUT
PB13.Signal=SPI2_SCK
PB14.Signal=SPI2_MISO
PB15.Signal=SPI2_MOSI
PC0.Signal=ADCx_IN10
PC1.Signal=ADCx_IN11
PC10.Signal=GPIO_Input
PC11.GPIO_Label=sd_cs
PC11.Signal=GPIO_Output
PC12.Signal=GPIO_Input
PC2.Signal=ADCx_IN12
PC3.Signal=ADCx_IN13
PC8.Signal=GPIO_Input
PC9.Signal=GPIO_Input
PD2.Signal=GPIO_Input
PD8.Signal=GPIO_Output
PD9.Signal=GPIO_Output

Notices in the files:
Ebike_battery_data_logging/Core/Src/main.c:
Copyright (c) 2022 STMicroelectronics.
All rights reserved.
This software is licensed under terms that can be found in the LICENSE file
